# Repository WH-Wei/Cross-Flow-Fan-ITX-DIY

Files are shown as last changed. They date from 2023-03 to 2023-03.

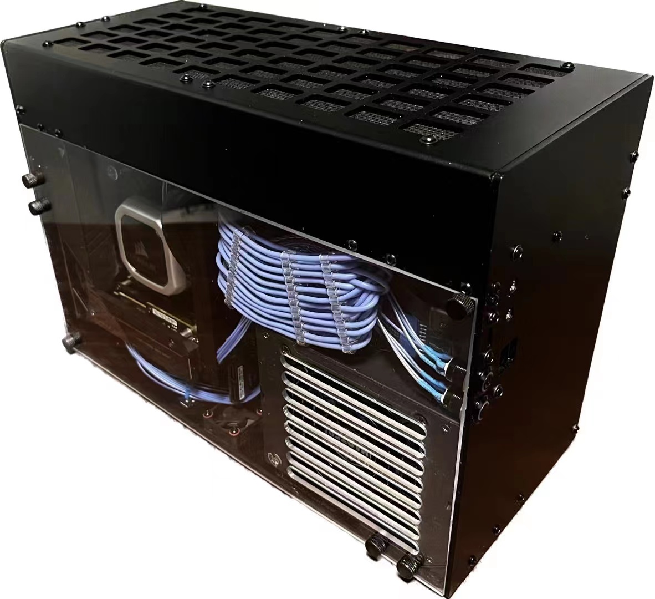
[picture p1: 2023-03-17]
图片/正侧图.jpg

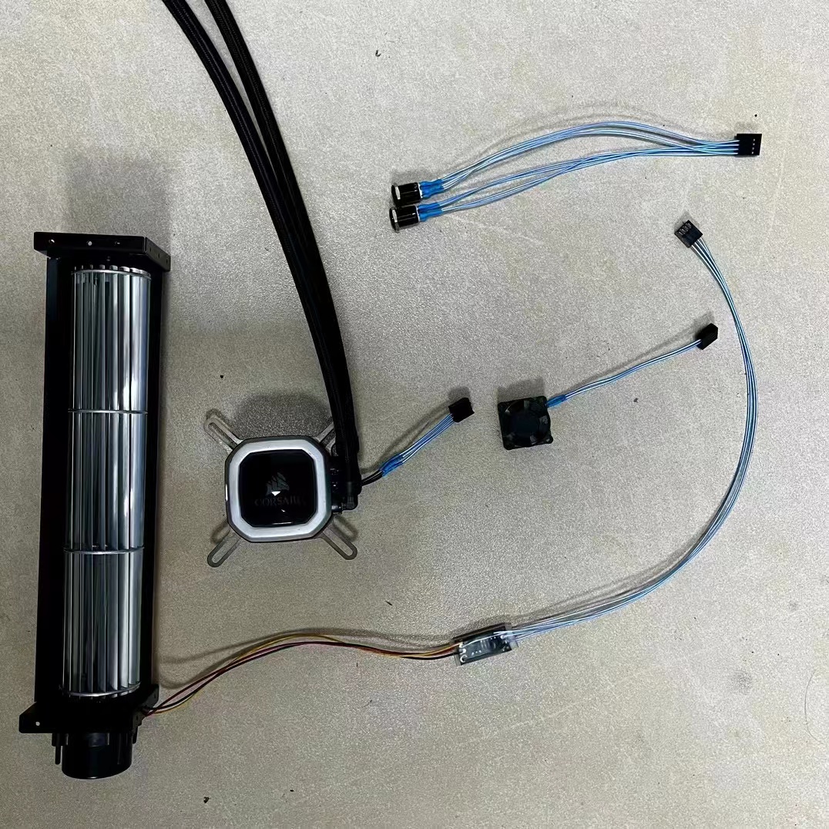
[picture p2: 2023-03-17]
图片/部分配件图.jpg

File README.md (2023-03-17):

# Cross-Flow-Fan-ITX-DIY
【简介】自己设计制作的11.5L ITX机箱（i7 13700kf + 4070ti），使用了贯流风机进行散热，灵感来自up立宗鸽鸽的视频。

【开源内容】此项目开源了图纸、加工文件和零件购买链接，还有成品照片可以查看。

【15分钟双烤压力测试】cpu满占用215瓦85度，核心90-95度； gpu满占用满功率，71度。

【注意】

1）此机箱为了使体积最小化而导致兼容性不强，如果使用其他型号的配件请自行确认图纸或修改图纸以实现适配。

2）基于此图纸进行的改进和测试请进行开源。

3）如果是修改图纸以适配不同的配件型号，也请将修改后的图纸进行开源，并说明其适配的配件型号。

4) 电源端因尺寸限制应使用插簧连接。
  
 -----------------------------------------------------------------------------------------------    
 
【具体配置】：

【cpu】13700kf

【显卡】4070ti 索泰x- gaming

【主板】ROG 690I

【电源】酷冷sfx850金牌

【冷排】Alphacool 280铜排 30厚

【冷头】改造海盗船i150pro

【水冷液】Absolute zero 4纳米银

【线缆】全模组定制线+所有面板定制线+风扇定制线

【机箱】自制贯流风机itx机箱11.5L（前面板10Ghz USB-A口两个，20Ghz USB-C口一个，耳机+麦克风孔）

【固态硬盘】p44pro 2T

【固态硬盘】sn850x 4T

【内存】三星DDR5 V07颗粒32G X 2条

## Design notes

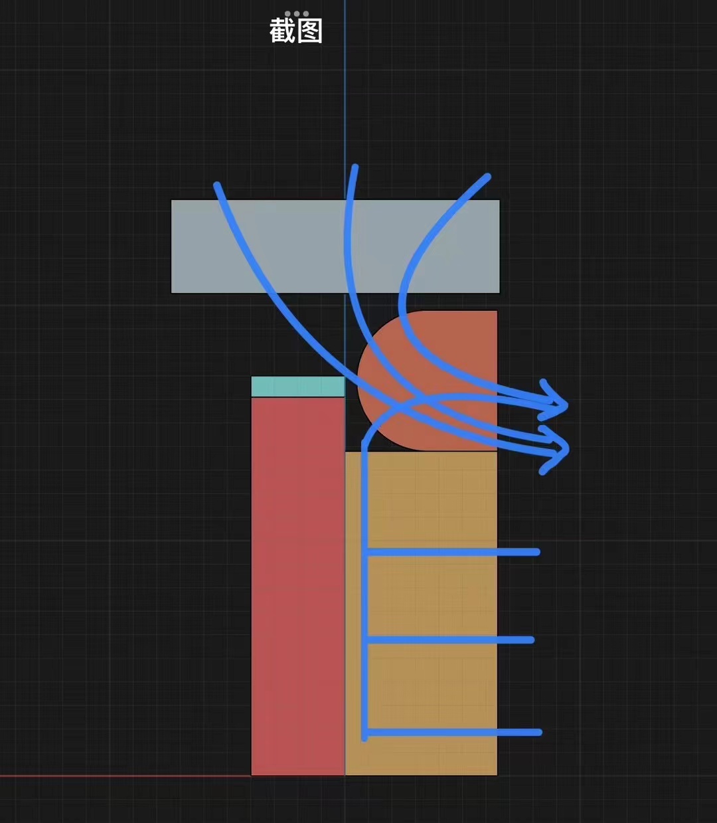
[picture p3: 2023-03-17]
图片/风道图.jpg

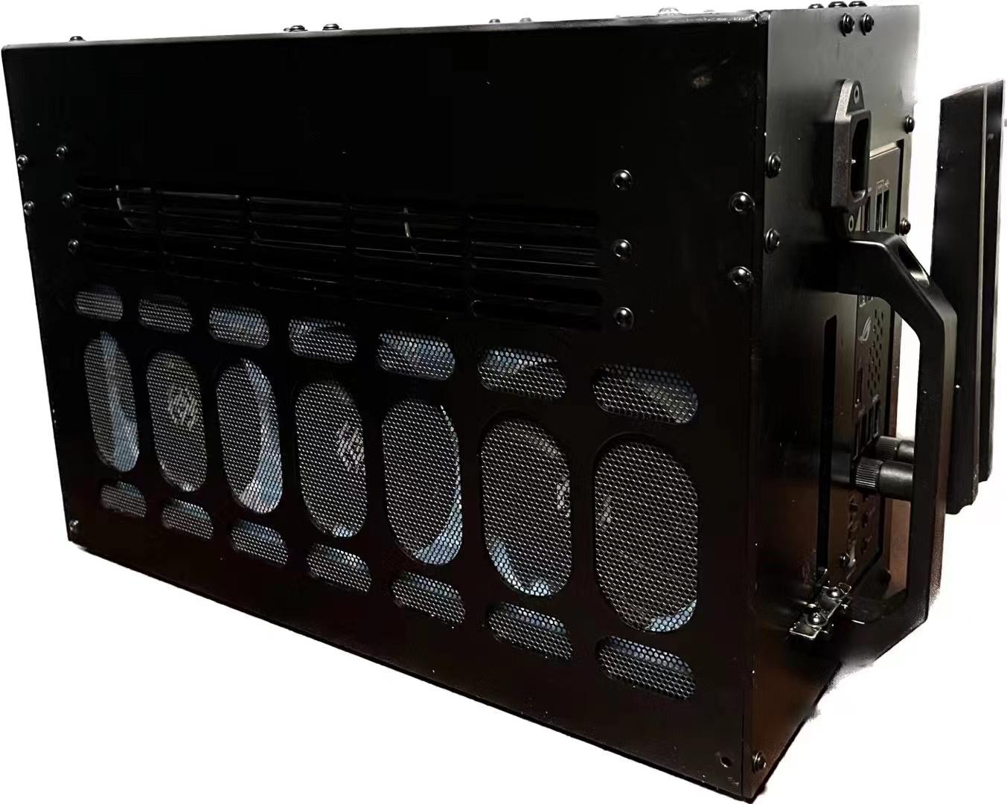
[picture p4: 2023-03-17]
图片/后侧图.jpg

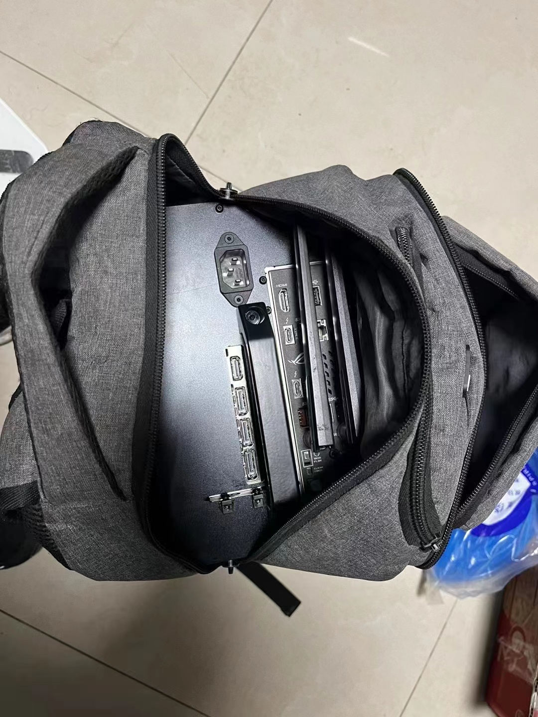
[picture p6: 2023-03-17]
图片/体积示意图.jpg

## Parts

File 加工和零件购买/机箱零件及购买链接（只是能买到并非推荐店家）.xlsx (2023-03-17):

类型 | 名称 | 型号 | 数量 | 单位 | 链接
定制类 | 3D打印件 | 文件夹：3打印 | 1 | 套 | https://www.wenext.cn/
 | PC板加工（建议在主板下方的位置增添一些进风口） | 文件夹：PC板加工 | 1 | 套 | https://item.taobao.com/item.htm?id=617669580473
 | 钣金加工 | 文件夹：钣金加工-喷砂120目-黑色氧化 | 1 | 套 | https://item.taobao.com/item.htm?id=702602902554
 | 定制线 | 文档：定制线规格表 | 1 | 套 | https://deepcolors.taobao.com/shop/view_shop.htm?
成品和半成品 | 把手 | 黑色130mm孔距 | 1 | 个 | https://detail.tmall.com/item.htm?id=680883631912
 | 防尘网 | 1.5MM孔 | 2 | 个 | https://item.taobao.com/item.htm?id=662737226971
 | 铝排连接件 | 黑色6*6*40mm4个M3铝氧化 | 18（含备用） | 个 | https://item.taobao.com/item.htm?id=655484508210
 | L型连接件 | 直角黑色支架（10*10*6） | 4（含备用） | 个 | https://item.taobao.com/item.htm?id=630186099365
 | 三线电源插座（量好尺寸后剪断使用） | C14带耳侧弯-C13左弯 0.6米 | 1 | 个 | https://detail.tmall.com/item.htm?id=666863651767&sku_properties=122216547:20213
 | 软管（灌水冷液用） | 内经6MM 外径10MM 透明 | 1 | 个 | https://item.taobao.com/item.htm?id=576866331770
 | 卡簧 | 管外径12MM（注意是管外径） | 2 | 个 | https://item.taobao.com/item.htm?id=521052790005
 | 90度弯头 | 90度双内丝弯头 黑色 | 1 | 个 | https://item.taobao.com/item.htm?id=521046386192
 | G1/4外牙直通 旋转对丝 | 黒色旋转对丝 | 1 | 个 | https://item.taobao.com/item.htm?id=535744328775
 | Granzon GD-45 45度旋转弯头 | 黑色 | 1 | 个 | https://item.taobao.com/item.htm?id=675400081419
 | 六面螺母四方 | 10*10*6（铝氧化黑色）M3 | 12（含备用） | 个 | https://item.taobao.com/item.htm?id=624653589494
 | 双通铝柱 | M3*10-D6 （1支）黑色 | 6（含备用） | 个 | https://detail.tmall.com/item.htm?id=598831579846
 | 单通铝柱 | M3*6+6 黑色 【10个】 | 1 | 个 | https://detail.tmall.com/item.htm?id=635465891592
 | 手拧螺钉 | M3*6-D10*6（10个）黑色网纹 | 1 | 个 | https://detail.tmall.com/item.htm?id=619143494015
 | 橡胶垫 | 12*7*3mm（10个） | 1 | 个 | https://item.taobao.com/item.htm?id=569193229531
 | 重启键 | 黑色重启键+60CM线线长：60CM开孔尺寸：12MM灯光颜色：黄 | 1 | 个 | https://item.taobao.com/item.htm?id=614370979327
 | 开机键 | 黑色开机键+60CM线线长：60CM开孔尺寸：12MM灯光颜色：白 | 1 | 个 | https://item.taobao.com/item.htm?id=614370979327
 | 机箱小风扇（感觉也可以不装） | 3cm（厚度1cm）12v静音 | 1 | 个 | https://item.taobao.com/item.htm?id=633511678693
 | 20Ghz高速USB线 | 黑色0.3米-全高挡板 | 1 | 个 | https://item.taobao.com/item.htm?id=595861436942
 | USB3.0接口 | 9针【母头】转2个USB3.0 | 1 | 个 | https://item.taobao.com/item.htm?id=557241621344
 | USB2.0接口 | 9针【母头】转2个USB2.0 | 1 | 个 | https://item.taobao.com/item.htm?id=557241621344
 | HD音频接口（需要diy改为弯角母座） | 单电路（不含线） | 1 | 个 | https://item.taobao.com/item.htm?id=564018026232
 | PWM控制器（如果4线风扇没货了可以买这个，有货不用买） | FR120N 隔离MOSFET MOS管 | 1 | 个 | https://detail.tmall.com/item.htm?id=641296094617
 | 贯流风机 | PA-43250DC12V | 1 | 个 | https://item.taobao.com/item.htm?id=557246911463
 | 水冷头 | 海盗船h150ipro单头3风扇 | 1 | 个 | https://item.taobao.com/item.htm?id=595623110750
 | 水冷头扣具 | h115iproh150Intelcpu显卡扣具 | 1 | 个 | https://item.taobao.com/item.htm?id=628278248251
 | 宝塔头（安装的时候记得先弄湿再插，会轻松很多） | 7.2MM宝塔外牙G1/4 | 2 | 个 | https://item.taobao.com/item.htm?id=670723908343
 | 电源线改装延长 | 3芯0.75平方 公+母 | 1 | 个 | https://item.taobao.com/item.htm?id=593623771250
 | 水冷头连接线（设置水冷灯光看水温用的，不设置不用买） | 长度：0.3m颜色分类：杜邦9Pin转右弯micro usb | 1 | 个 | https://detail.tmall.com/item.htm?id=624146993672
紧固件（会有很多剩余，懒得整理具体数量了） | 黑色304不锈钢圆头内六角螺丝 | M3*8 (20粒) | 3 | 个 | https://detail.tmall.com/item.htm?id=17045767639
 |  | M3*12 (10粒) | 2 | 个
 |  | M3*6 (20粒) | 3 | 个
 |  | M3*10 (20粒) | 2 | 个
 |  | M3*16 (10粒) | 2 | 个
 |  | M3*18 (50个) | 1 | 个
 |  | M3*5 (20粒) | 2 | 个
 | 黑色304不锈钢沉头内六角螺丝钉 | M3*6 (20粒) | 1 | 个 | https://detail.tmall.com/item.htm?id=22084872765
 |  | M5*16 (5粒) | 1 | 个
 | 垫片 | M3*7*0.5 (200个) | 1 | 个 | https://detail.tmall.com/item.htm?id=19638820764
建议搭配此机箱的电脑配件 | 主板 | ASUS/华硕 ROG STRIX Z690-I GAMING WIFI 猛禽 ITX迷你 DDR5主板 | 1 | 个
 | 显卡 | 索泰RTX4070Ti XGAMING | 1 | 个
 | 冷排 | Alphacool 280冷排HPE-30厚度 | 1 | 个
其他常备耗材 | 插簧
 | 轧带
 | 自粘轧带固定座
 | 热缩管

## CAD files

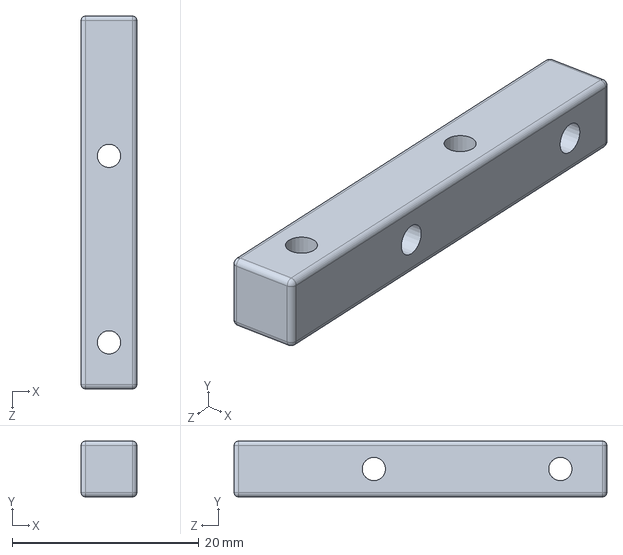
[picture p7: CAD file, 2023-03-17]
solidworks版本图纸/6x6x40_M3.SLDPRT
6.00 x 6.00 x 40.0 mm

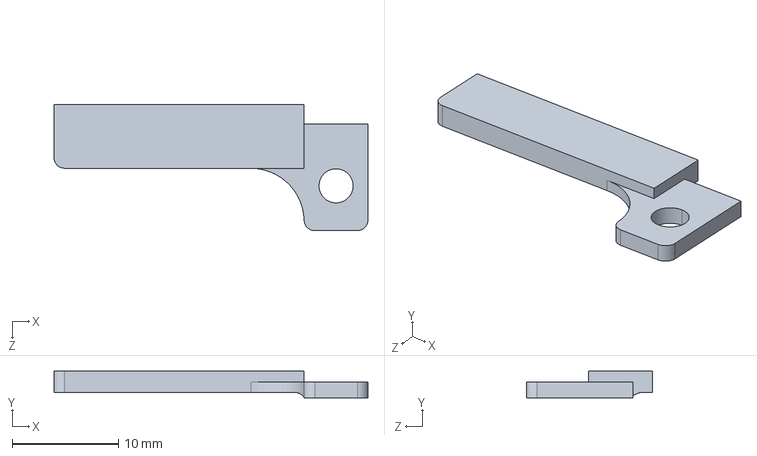
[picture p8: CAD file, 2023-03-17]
加工和零件购买/3D打印/底盖-黑色尼龙.STEP
29.5 x 2.50 x 11.9 mm

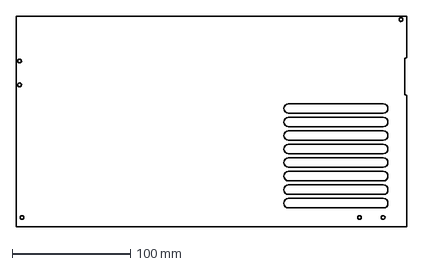
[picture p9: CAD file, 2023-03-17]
加工和零件购买/PC板加工/侧板-PC-2mm厚.DXF
330.0 x 178.0 mm

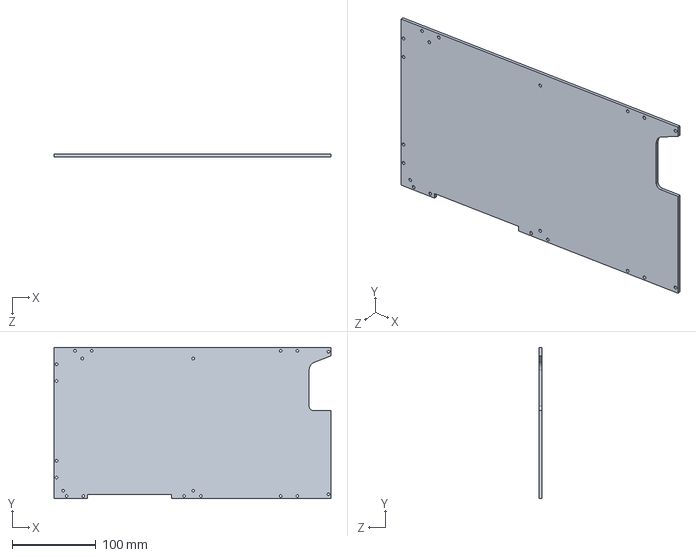
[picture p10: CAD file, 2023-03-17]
加工和零件购买/钣金加工-喷砂120目-黑色氧化/中板-5051-3mm厚/中板.STEP
330.0 x 180.0 x 3.00 mm

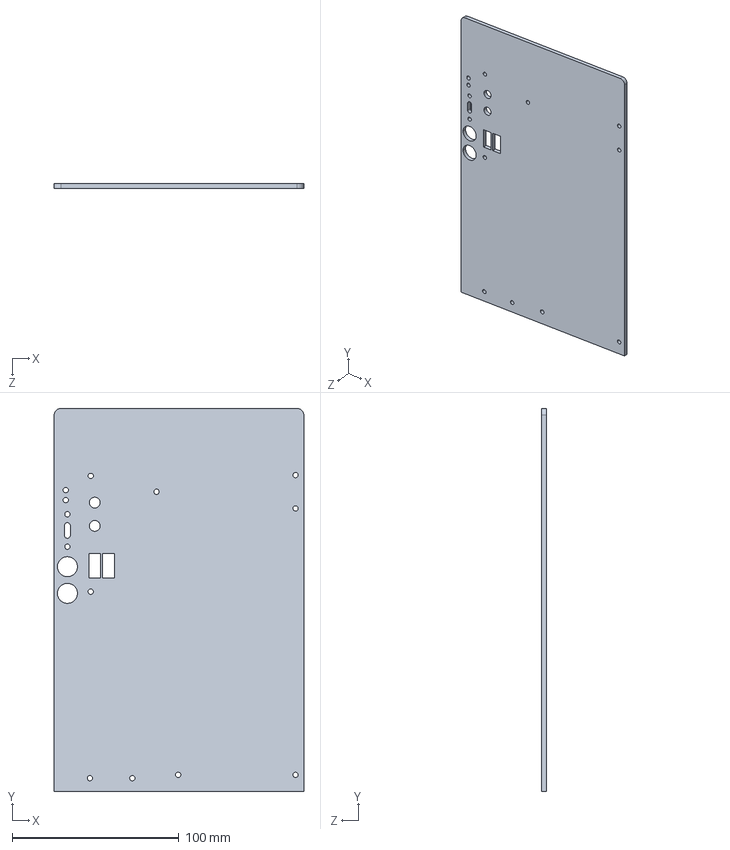
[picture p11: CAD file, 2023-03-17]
加工和零件购买/钣金加工-喷砂120目-黑色氧化/前面板-5051-3mm厚/前面板.STEP
150.0 x 230.0 x 3.00 mm

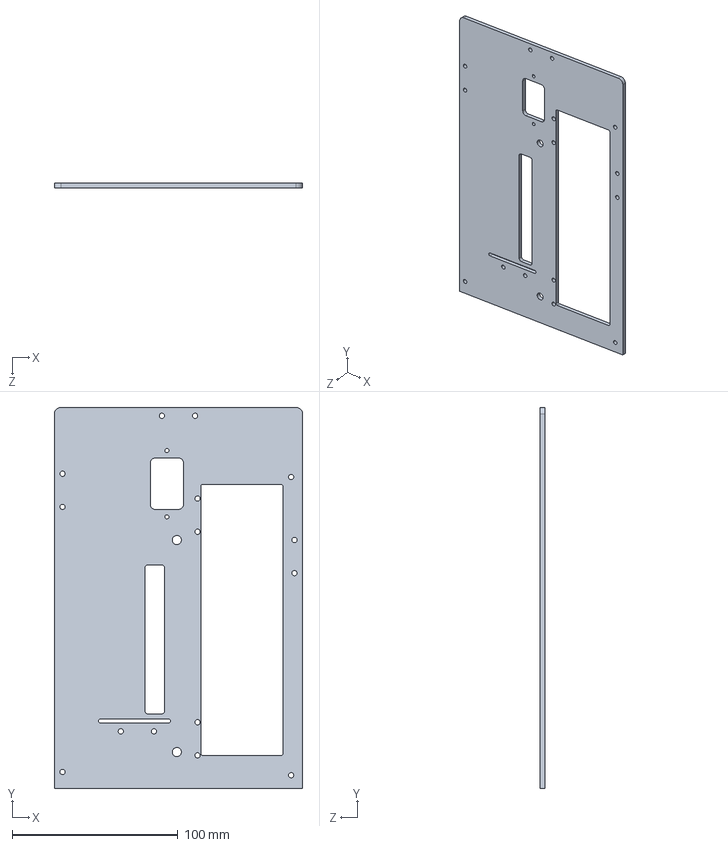
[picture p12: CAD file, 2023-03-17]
加工和零件购买/钣金加工-喷砂120目-黑色氧化/后面板-5051-3mm厚（2个2点5mm孔是M3螺纹）/后面板.STEP
150.0 x 230.0 x 3.00 mm

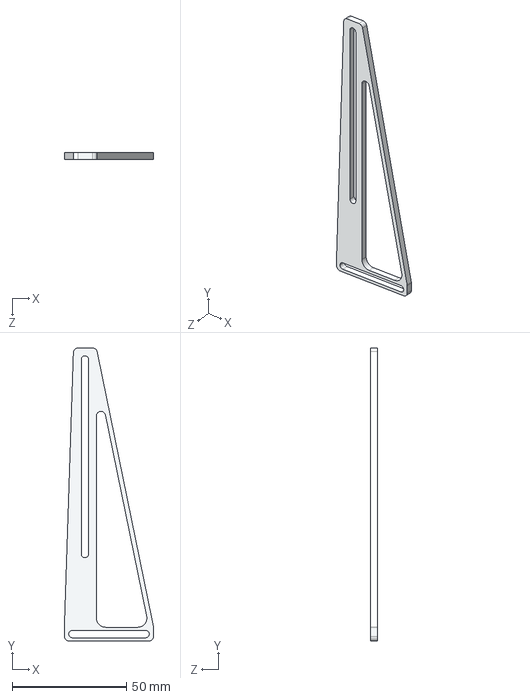
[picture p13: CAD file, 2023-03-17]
加工和零件购买/钣金加工-喷砂120目-黑色氧化/尺寸调节板-5051-3mm厚/尺寸调节板.STEP
39.0 x 128.0 x 3.00 mm

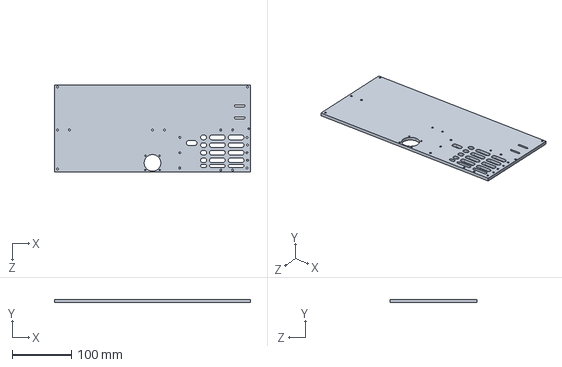
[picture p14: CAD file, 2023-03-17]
加工和零件购买/钣金加工-喷砂120目-黑色氧化/底板-5051-5mm厚（4个2点5mm孔是M3螺纹）/机箱底板.STEP
330.0 x 5.00 x 146.0 mm

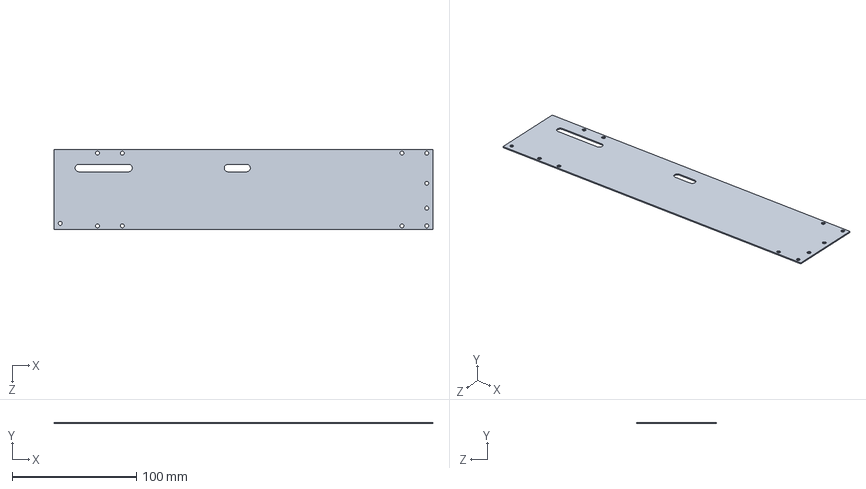
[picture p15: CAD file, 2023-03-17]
加工和零件购买/钣金加工-喷砂120目-黑色氧化/阻隔板中板-5051-1mm厚/阻隔板中板.STEP
305.0 x 1.00 x 64.5 mm

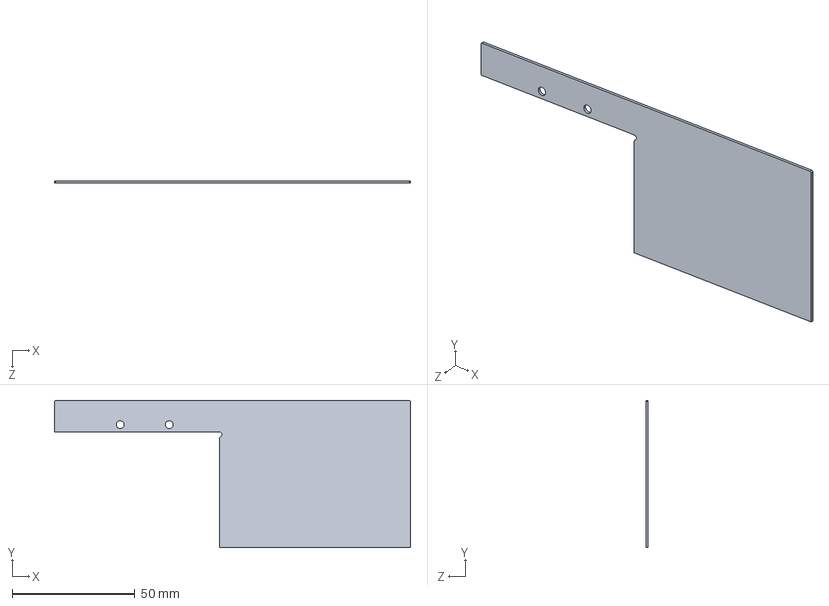
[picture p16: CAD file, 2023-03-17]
加工和零件购买/钣金加工-喷砂120目-黑色氧化/阻隔板侧板-5051-1mm厚/阻隔板侧板.STEP
145.0 x 60.0 x 1.00 mm

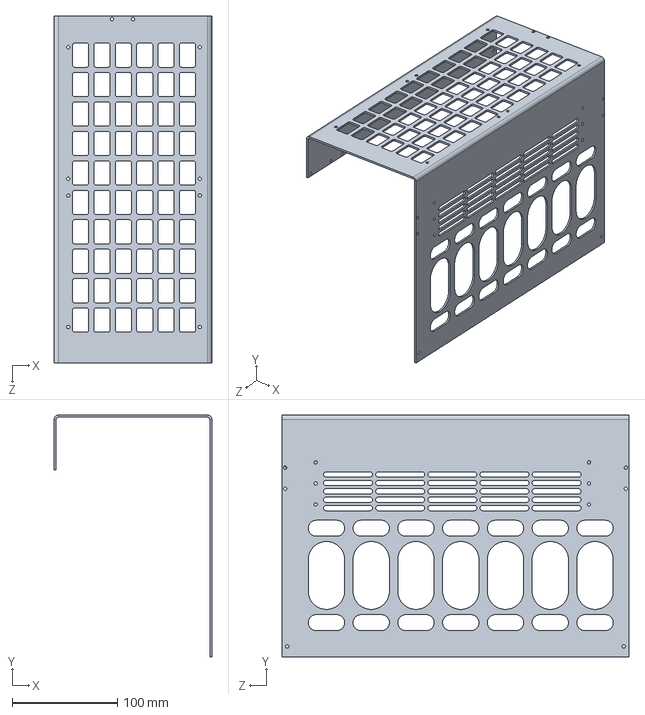
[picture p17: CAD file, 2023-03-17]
加工和零件购买/钣金加工-喷砂120目-黑色氧化/顶板-5051-2mm厚-折弯/顶板.STEP
150.0 x 230.0 x 330.0 mm

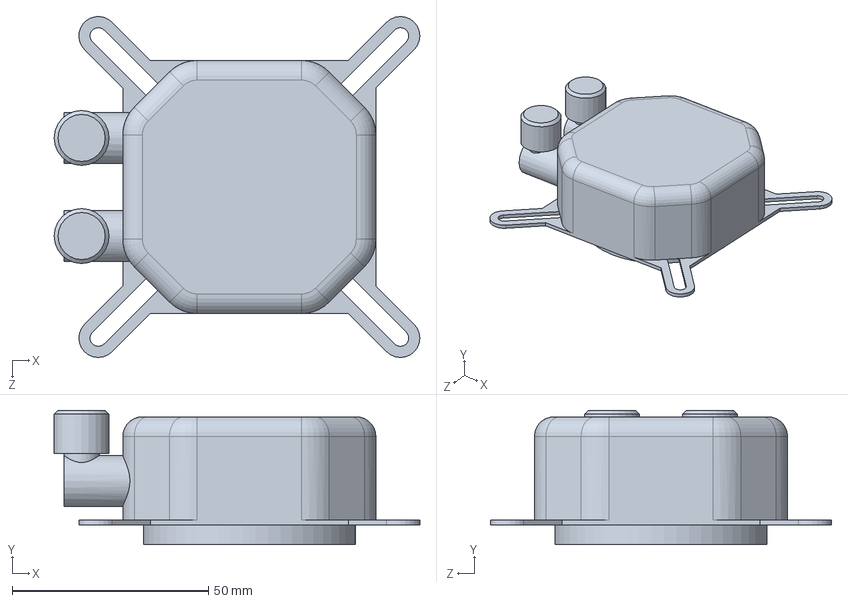
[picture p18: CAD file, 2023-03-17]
solidworks版本图纸/海盗船h150ipro.SLDPRT
93.2 x 34.2 x 86.9 mm

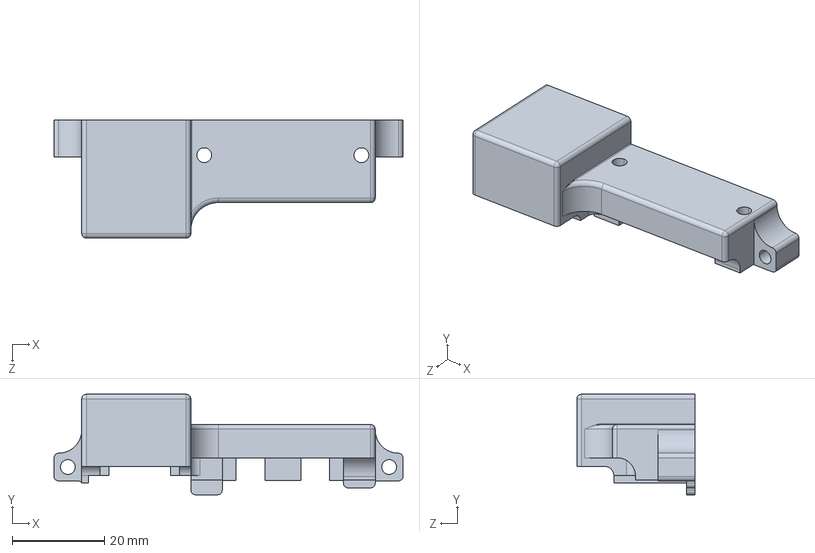
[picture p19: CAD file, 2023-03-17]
加工和零件购买/3D打印/壳体-黑色尼龙.STEP
75.5 x 21.7 x 25.6 mm

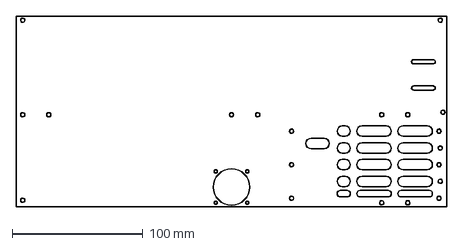
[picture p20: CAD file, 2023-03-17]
加工和零件购买/钣金加工-喷砂120目-黑色氧化/底板-5051-5mm厚（4个2点5mm孔是M3螺纹）/底板.DXF
330.0 x 146.0 mm

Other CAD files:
solidworks版本图纸/显卡防尘网.SLDPRT
solidworks版本图纸/铜柱_发黑_3x6+6.SLDPRT
solidworks版本图纸/M3_D6_10.SLDPRT
solidworks版本图纸/机箱后板.SLDPRT
solidworks版本图纸/10_10_6铝方M3.SLDPRT
solidworks版本图纸/30mm风扇.SLDPRT
solidworks版本图纸/7mmG4宝塔头.SLDPRT
solidworks版本图纸/Alphacool280HPE-30.SLDPRT
solidworks版本图纸/CoolerMaster_sfx_V850.SLDPRT
solidworks版本图纸/M3_90度角码_10.SLDPRT
solidworks版本图纸/PA_43250DC12.SLDPRT
solidworks版本图纸/ROG_STRIX_Z690I.SLDPRT
solidworks版本图纸/USB3Gen2x2.SLDPRT
solidworks版本图纸/前面板.SLDPRT
solidworks版本图纸/开关机键12mm.SLDPRT
solidworks版本图纸/显卡支架.SLDPRT
solidworks版本图纸/机箱中板.SLDPRT
solidworks版本图纸/机箱侧板.SLDPRT
solidworks版本图纸/机箱前板.SLDPRT
solidworks版本图纸/机箱底板.SLDPRT
solidworks版本图纸/机箱顶板.SLDPRT
solidworks版本图纸/机箱风道前隔板.SLDPRT
solidworks版本图纸/机箱风道隔板.SLDPRT
solidworks版本图纸/电源插座.SLDPRT
solidworks版本图纸/重启键.SLDPRT
加工和零件购买/钣金加工-喷砂120目-黑色氧化/中板-5051-3mm厚/中板.DXF
加工和零件购买/钣金加工-喷砂120目-黑色氧化/前面板-5051-3mm厚/前面板.DXF
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
